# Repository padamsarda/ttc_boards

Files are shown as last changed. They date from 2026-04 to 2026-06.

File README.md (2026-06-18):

# Arduino TTC Shield

## Overview
This Arduino shield was made for testing and learning TTC systems. It combines both the nRF24L01 and LoRa RA-02 modules on a single board, making it easy to switch between short- and long-range wireless communication during development.

The board also includes an INA219 for power tracking, understanding the relation between Link-Budget and Power-Budget.

## Features
- Arduino Uno shield form factor
- nRF24L01 wireless module interface
- LoRa RA-02 module interface
- INA219 current sensing
- Jumper-selectable power for nRF24L01
- Jumper-selectable power for LoRa
- Boost converter for battery operation
- Battery connector
- Power indicator LED

## Applications
- TTC (Telemetry, Tracking and Command) development
- learning LoRa RA-02 and NRF24L01 
- Power consumption measurement of RF modules
- Rapid prototyping with Arduino

## Notes
This was my first actual pcb, made a few mistakes too
Designed and developed as part of **Team Anant**.

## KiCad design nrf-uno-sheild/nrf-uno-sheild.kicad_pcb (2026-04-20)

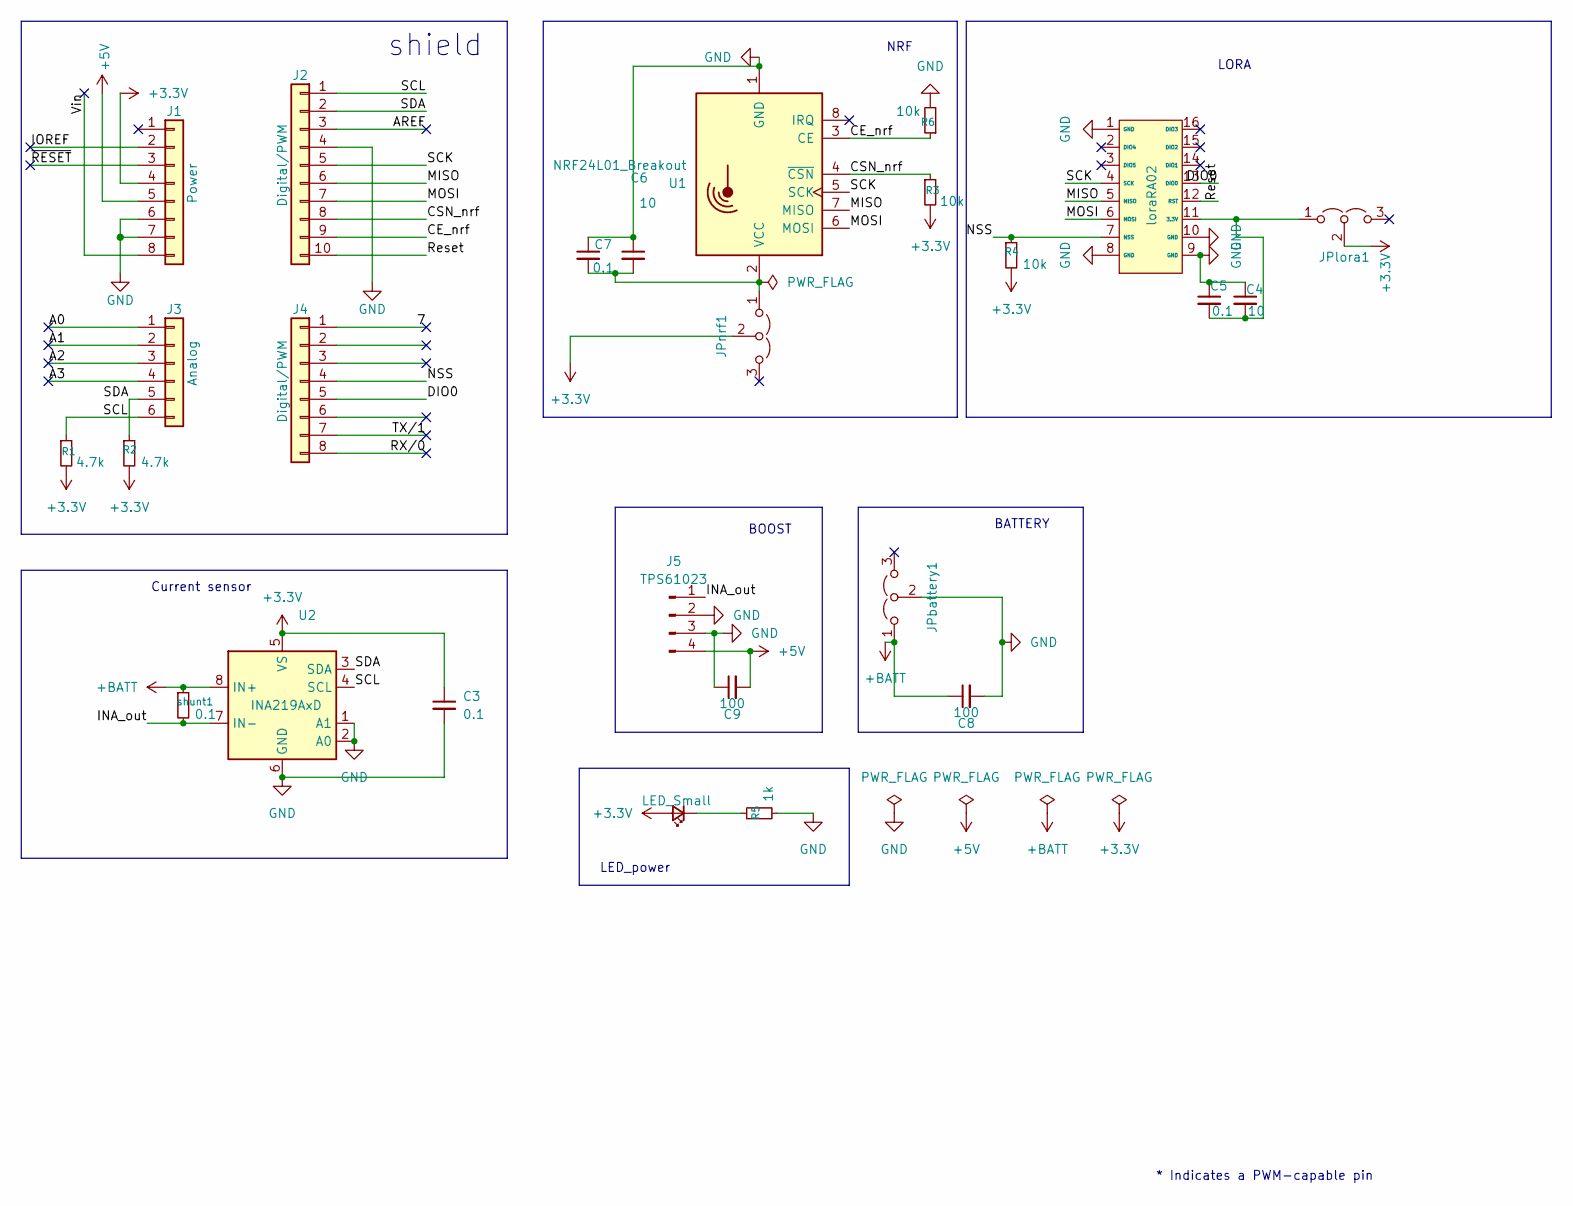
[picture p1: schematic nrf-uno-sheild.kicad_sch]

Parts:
C3, C5, C7: 0.1; C_0805_2012Metric
C4, C6: 10; C_0805_2012Metric
C8, C9: 100; C_0805_2012Metric
D1: LED_Small; LED_D3.0mm
J1: Power; PinSocket_1x08_P2.54mm_Vertical
J2: Digital/PWM; PinSocket_1x10_P2.54mm_Vertical
J3: Analog; PinSocket_1x06_P2.54mm_Vertical
J4: Digital/PWM; PinSocket_1x08_P2.54mm_Vertical
J5: TPS61023; PinHeader_1x04_P2.54mm_Vertical
JPbattery1: Jumper_3_Open; PinHeader_1x03_P2.54mm_Vertical
JPlora1: Jumper_3_Open; PinHeader_1x03_P2.54mm_Vertical
JPnrf1: Jumper_3_Open; PinHeader_1x03_P2.54mm_Vertical
R1, R2: 4.7k; R_0805_2012Metric
R3, R4, R6: 10k; R_0805_2012Metric
R5: 1k; R_0805_2012Metric
U1: NRF24L01_Breakout; nRF24L01_Breakout
U2: INA219AxD; SOIC-8_3.9x4.9mm_P1.27mm
loraRA02: loraRA02 breakout
shunt1: 0.1; R_2512_6332Metric

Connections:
+3.3V: C3.1, D1.2 (A), J1.4, JPlora1.2 (C), JPnrf1.2 (C), R1.2, R2.2, R3.2, R4.2, U2.5 (VS); also elsewhere on the board
+5V: C9.2, J1.5, J5.4
+BATT: C8.1, JPbattery1.1 (A), U2.8 (IN+), shunt1.1
/7: J4.1
/A0: J3.1
/A1: J3.2
/A2: J3.3
/A3: J3.4
/AREF: J2.3
/CE_nrf: J2.9, R6.1, U1.3 (CE); also elsewhere on the board
/CSN_nrf: J2.8, R3.1, U1.4 (~CSN); also elsewhere on the board
/DIO0: J4.5, loraRA02.13 (DIO0)
/INA_out: J5.1, U2.7 (IN-), shunt1.2
/IOREF: J1.2
/MISO: J2.6, U1.7 (MISO), loraRA02.5 (MISO); also elsewhere on the board
/MOSI: J2.7, U1.6 (MOSI), loraRA02.6 (MOSI); also elsewhere on the board
/NSS: J4.4, R4.1, loraRA02.7 (NSS)
/RX/0: J4.8
/Reset: J2.10, loraRA02.12 (RST)
/SCK: J2.5, U1.5 (SCK), loraRA02.4 (SCK); also elsewhere on the board
/SCL: J2.1, J3.6, R1.1, U2.4 (SCL)
/SDA: J2.2, J3.5, R2.1, U2.3 (SDA)
/TX/1: J4.7
/Vin: J1.8
/~RESET: J1.3
GND: C3.2, C4.1, C5.1, C6.1, C7.1, C8.2, C9.1, J1.6, J1.7, J2.4, J5.2, J5.3, JPbattery1.2 (C), R5.2, R6.2, U1.1 (GND), U2.1 (A1), U2.2 (A0), U2.6 (GND), loraRA02.1 (GND), loraRA02.8 (GND), loraRA02.9 (GND), loraRA02.10 (GND); also elsewhere on the board
unnamed: D1.1 (K), R5.1
unnamed: C4.2, C5.2, JPlora1.1 (A), loraRA02.11 (3.3V)
unnamed 28: C6.2, C7.2, JPnrf1.1 (A), U1.2 (VCC); also elsewhere on the board

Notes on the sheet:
Current sensor
BOOST
LORA
NRF
BATTERY
shield
LED_power
* Indicates a PWM-capable pin

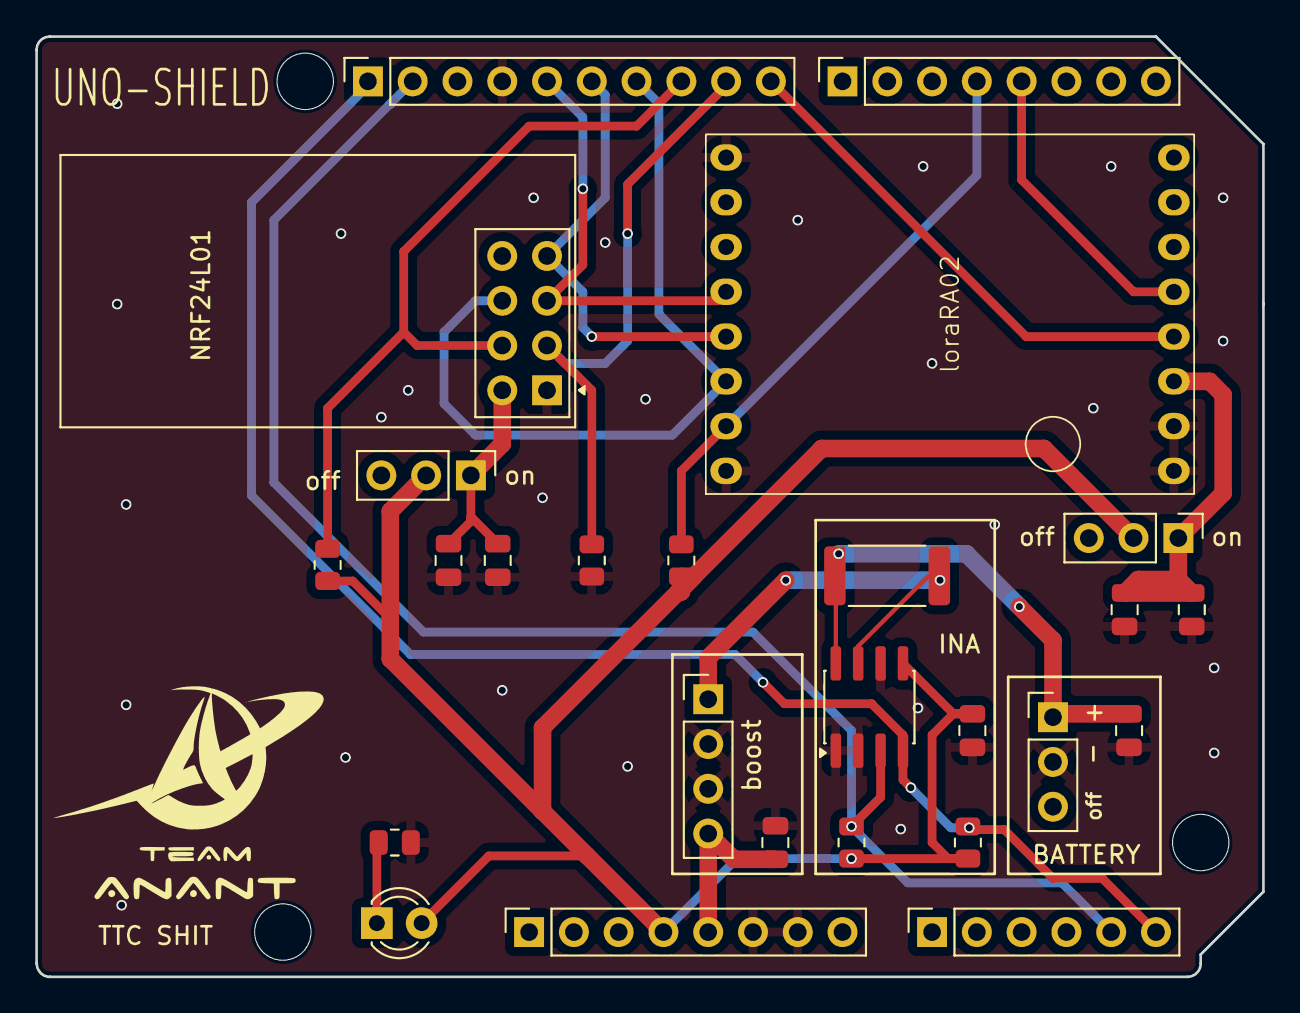
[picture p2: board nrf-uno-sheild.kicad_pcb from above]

Board: 2 copper layers, 69.6 x 53.3 mm, 29 parts (0 on the bottom side), 18 nets.

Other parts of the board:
MH1, MH2, MH4: MountingHole_3.2mm
on: Jumper_3_Open; PinHeader_1x03_P2.54mm_Vertical
u1: NRF24L01_Breakout; nRF24L01_Breakout

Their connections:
+3.3V: on.2 (C); also elsewhere on the board
/CE_nrf: u1.3 (CE); also elsewhere on the board
/CSN_nrf: u1.4 (~CSN); also elsewhere on the board
/MISO: u1.7 (MISO); also elsewhere on the board
/MOSI: u1.6 (MOSI); also elsewhere on the board
/SCK: u1.5 (SCK); also elsewhere on the board
GND: u1.1 (GND); also elsewhere on the board
unnamed 28: on.1 (A), u1.2 (VCC); also elsewhere on the board
